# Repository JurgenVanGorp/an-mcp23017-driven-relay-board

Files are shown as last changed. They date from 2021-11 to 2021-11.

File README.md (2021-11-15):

Guide creation date: 13-Nov-2021

# An MCP23017 driven relay board for Home Assistant on a Raspberry Pi
A schematic and hardware board for an MCP23017 multi-I/O controller driven relays.

Previous topic: [Step 4: Controlling the MCP23017 from within Home-Assistant.](https://github.com/JurgenVanGorp/MCP23017-multi-I-O-Control-with-Raspberry-Pi-and-Home-Assistant)

## Introduction

In the previous topics it was shown how an MCP23017 can be used for controlling toggle relays with an MCP23017 multi-I/O chip. The examples made use of an MCP23017 chip on a breadboard. For real life usage we will need a PCB that can be properly installed in a rack.

This guide describes a simple PCB board in Eurocard format (10cm x 16cm) that allows connecting an MCP23017 to a Raspberry Pi with Home Assistant, over the I2C bus. The board has 15 open ended relays. The 16th output is used to drive an "identification" LED. It can be used to identify the board if you are using multiple boards, and for verification that the communication is working properly.

The board needs a 12V power supply. The 12V is converted to 5V on the board, and is also used to power the mini relays. With some modifications you can also use the board with 5V directly, but you would need to replace the relays with pin-compatible 5V relays. I am using 12V for the simple reason that all switches in my house operate on 12V. The translation to higher voltages is only done in the power box.

**WARNING** Even though the PCB board described below does provide you with physical segregation with relays, IT IS NOT SUITED FOR HIGH VOLTAGE OR HIGH CURRENT USE. The low voltage and high voltage lines on the PCB are not sufficiently separated on the PCB for safe use with high voltages. The board can be used with low-voltage (max 48V) toggle relays (aka teleruptors) at a maximum of 500 milliAmps.

## Using and changing the files in this repository

I have created the schematic and PCB in this repository with the open and free [KiCad EDA](https://www.kicad.org/) software. I cannot express enough how much I am grateful to [the developers](https://www.kicad.org/about/kicad/) of this PCB software. As far as I'm concerned the times of too-expensive PCB software are over.

The PCB file looks as follows.

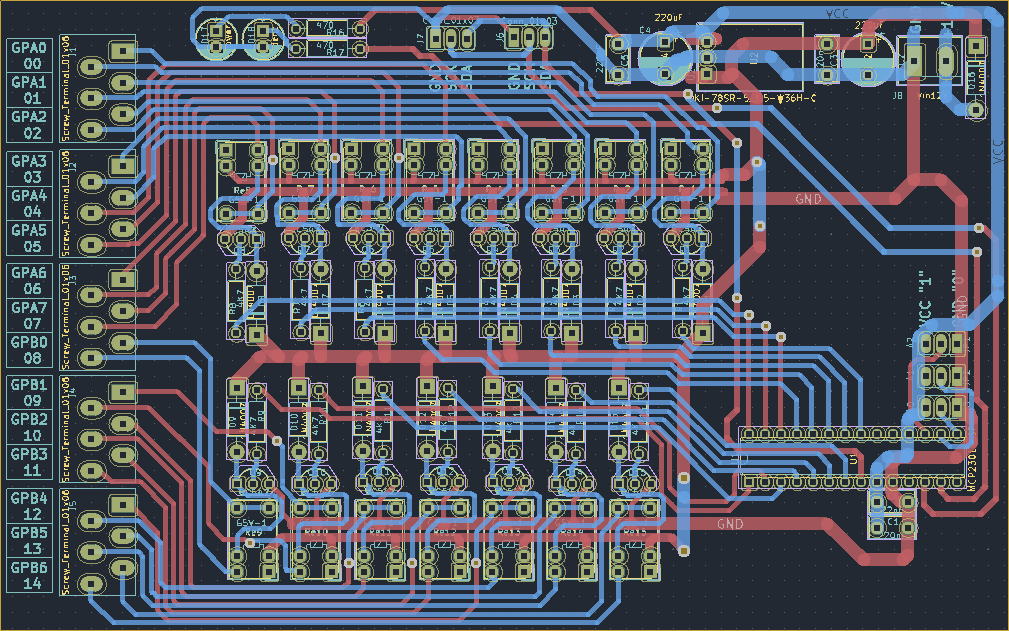
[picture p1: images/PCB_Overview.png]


The GERBER PCB Files are included in the package, so you don't need to compile these for yourself.

There are many companies that will be able to create the PCB files for you. My personal favorite is [Eurocircuits.eu](https://www.eurocircuits.com/), but that's a personal choice of course. You can also create your own PCBs; the PDF file is added in the repository. But let's be honest, ordering the PCB looks a lot more professional and will last longer.



**INFO** In honnesty: the image above does not fully match the PCB you can find in the repository. In this prototype I made use of RJ10 connectors for the I2C connections, but these connectors are difficult to find. If you find one, it will probably have a slightly footprint. For that reason I used 'standard' 3-pin connectors in the final PCB layout.

## Components used.

This is the list of components used, and where I have found them.

| Quantity | Component | Value | Source | ~cost/Piece |
|:---:|---|---:|---|---:|
| 1 | PCB Board | See Gerber files | [eurocircuits.eu](https://www.eurocircuits.eu) | € 35.00 | 
| 1 | IC | MCP23017 | [mouser.com](https://eu.mouser.com/ProductDetail/Microchip/MCP23017-E-SP?qs=sGAEpiMZZMsVgcksf1EMUq%252Bl%252ByrW%252Br2s) | € 1.35 |
| 2 | 14 pins socket | MCP23017 | [mouser.com](https://www.conrad.com/p/tru-components-ic-socket-contact-spacing-254-mm-762-mm-number-of-pins-14-1-pcs-1568704) | € 0.40 |
| 2 | Resistor | 470 |  |  | 
| 16 | Diode | 1N4007 | [conrad.com](https://www.conrad.com/p/diotec-si-rectifier-1n4007-do-204al-1000-v-1-a-162272) | € 0.09 | 
| 15 | Resistor | 4K7 | [conrad.com](https://www.conrad.com/p/tru-components-tc-mf0w4ff4701a50203-metal-film-resistor-47-k-axial-lead-0207-025-w-1-1-pcs-1585059) | € 0.10 | 
| 1 | Capacitor | 22nF  | [conrad.com](https://www.conrad.com/p/tru-components-tc-k22nf5-ceramic-capacitor-tht-22-nf-100-v-20-1-pcs-1589451) | € 0.10 | 
| 3 | Capacitor | 220nF | [conrad.com](https://www.conrad.com/p/kemet-c320c224m5u5ta-ceramic-capacitor-radial-lead-220-nf-50-v-20-l-x-w-x-h-508-x-318-x-584-mm-1-pcs-1420328) | € 0.60 | 
| 2 | Capacitor | 220uF | [conrad.com](https://www.conrad.com/p/europe-chemicon-eky-500ell221mj16s-electrolytic-capacitor-radial-lead-5-mm-220-f-50-v-20-x-h-10-mm-x-16-mm-1-pc-1505568) | € 0.50 | 
| 15 | Transistor | BC547 **(1)** | [conrad.com](https://www.conrad.com/search?search=140539&searchType=regular) | € 0.05 |
| 1 | 12V to 5V DC | OKI-78SR-5_1.5-W36H-C **(2)** | [mouser.com](https://eu.mouser.com/ProductDetail/Murata/OKI-78SR-5-15-W36H-C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) | € 3.64 | 
| 15 | Relay 12V | G5V-1-DC12 **(3)** | [mouser.com](https://eu.mouser.com/ProductDetail/Omron/G5V-1-DC12?qs=sGAEpiMZZMv0NwlthflBi%2Fae0vpIDW5L) | € 1.45 |
| 3 | Jumper | N/A | e.g. [conrad.com](https://www.conrad.com/p/tru-components-shorting-jumper-contact-spacing-254-mm-pins-per-row2-content-100-pcs-1693950) | € 0.35 | 
| 1 | Connector 1x2 | DG350-3.5-03P | [conrad.com](https://www.conrad.com/p/degson-dg350-35-02p-14-00ah-200-screw-terminal-2-mm-number-of-pins-2-green-200-pcs-1595136) | € 0.22 | 
| 2 | Connector 1x3 | DG350-3.5-02P | [conrad.com](https://www.conrad.com/p/degson-dg350-35-03p-14-00ah-200-screw-terminal-2-mm-number-of-pins-3-green-200-pcs-1595217) | € 0.32 | 
| 5 | 1x6 Spring connector | PTR 54191060051E | [conrad.com](https://www.conrad.com/p/ptr-54191060051e-spring-loaded-terminal-075-mm-number-of-pins-6-pebble-grey-1-pcs-569770) | € 0.36 | 
| 1 | LED "IDENT"  | Green 5 mm | [conrad.com](https://www.conrad.com/p/vishay-tlhr-5400-led-wired-super-red-circular-5-mm-10-mcd-30-30-ma-2-v-184389) | € 0.20 | 
| 1 | LED "POWER"  | Red 5 mm | [conrad.com](https://www.conrad.com/p/kingbright-l-7113id-led-wired-red-circular-5-mm-45-mcd-30-20-ma-2-v-180139) | € 0.20 |
| TOTAL | | | | ~€ 74 |

**(1)** Also known as 2N3904 / BC547 / PN2222 / 2N4401 / NTE123AP. Make your pick, this is a "standard" NPN transistor. 

**(2)** The OKI-78SR is a 12V DC to 5V DC converter. It is pin-compatible with an [LM7805](https://eu.mouser.com/ProductDetail/Texas-Instruments/LM7805CT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). The current drawn is very low, so feel free to replace it with an LM7805 if you prefer.

**(3)** You can also power the board with 5V. In that case you will need to bridge the DC/DC converter and replace the 12V relays with the 5V [G5V-1-DC5 version](https://eu.mouser.com/ProductDetail/Omron/G5V-1-2-DC5?qs=sGAEpiMZZMsKEdP9slC0YbH1hXJZnuIH7AhUMezYhKg%3D).

The assembled board should look something like the following. Please mind that the below board is the prototype and looks slightly different from the PCB.

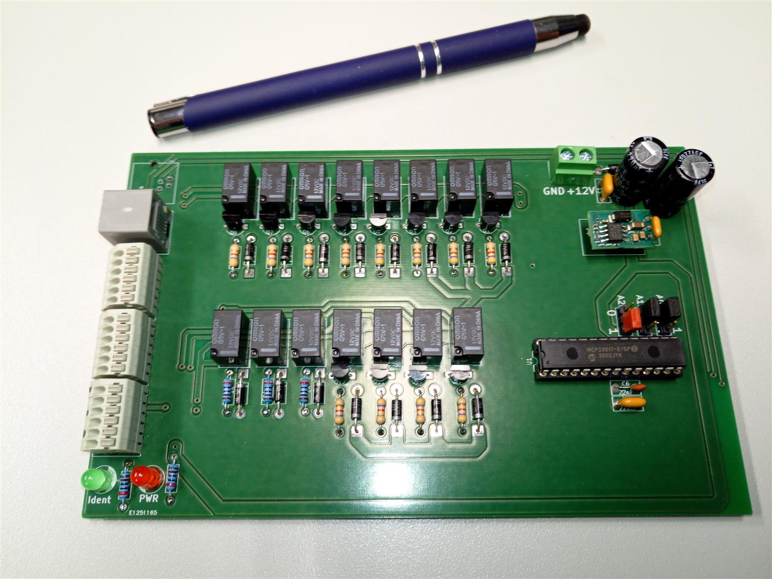
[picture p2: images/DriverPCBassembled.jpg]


## Schematic decription

The overall schematic looks as follows. You can [download the shematic in PDF format here](https://github.com/JurgenVanGorp/an-mcp23017-driven-relay-board/blob/main/DOMOTICS%20MCP23017%20Relay%20Control/PCB%20Layouts.pdf).

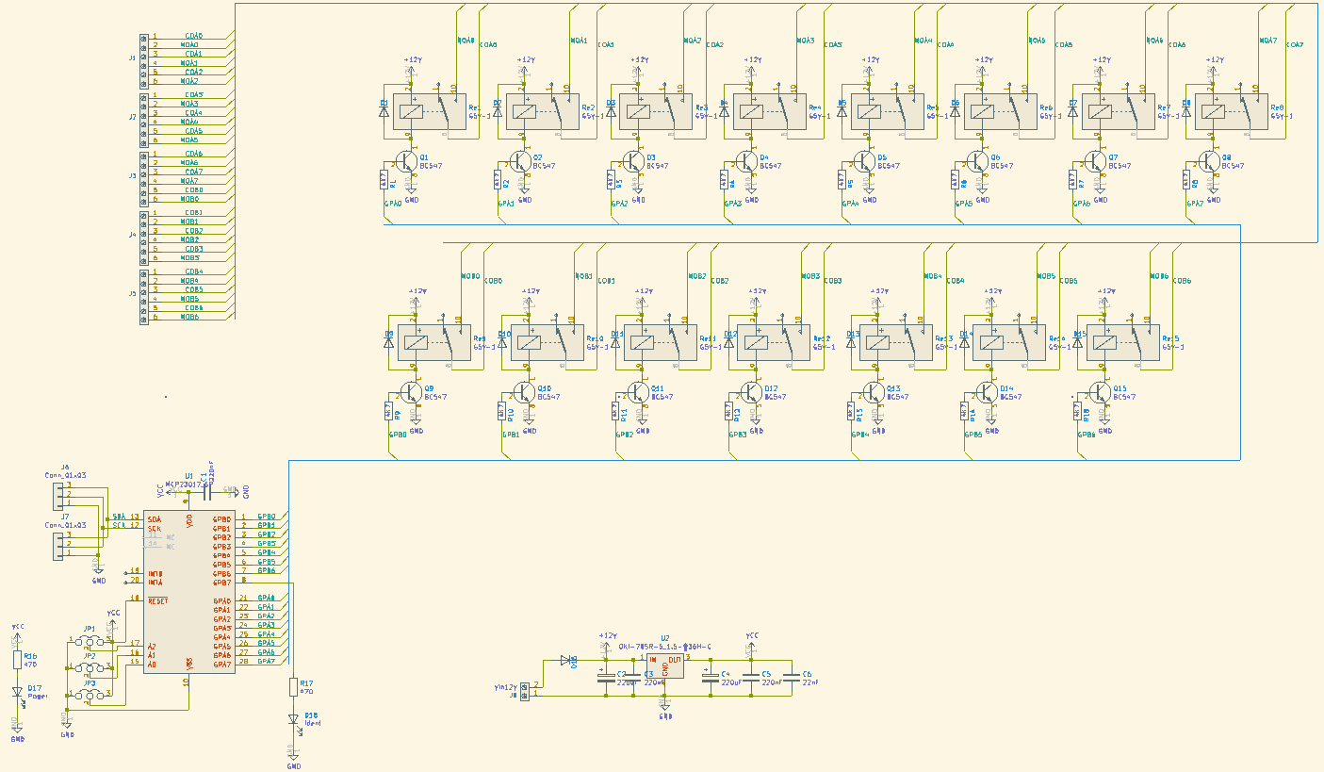
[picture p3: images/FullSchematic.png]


True, this is a bit crowded, and not easy to follow. So, let's highlight a few details here. The easy part is the top left section, containing the connector block with five 6-pins spring connectors.

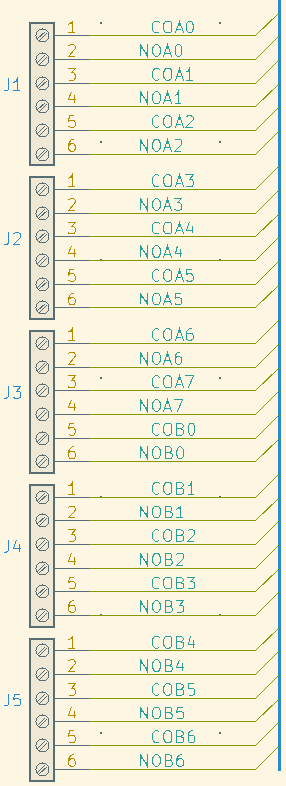
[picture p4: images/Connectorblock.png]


Then, let's have a look at one of the fifteen relay configurations you can find in the top right section of the schematic.

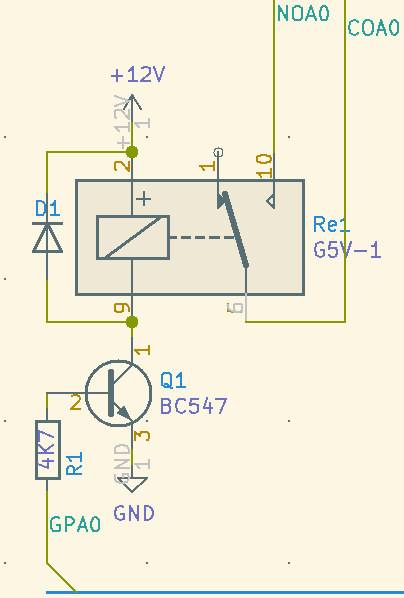
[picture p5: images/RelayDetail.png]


All fifteen relays have the same straight-forward configuration.
* The NO (Normally-Open) and CO (Common) pins of the relay are routed to the connector block. I.e. 'in rest' the outputs are not connected.
* Resistor R1 is connected to the output of one of the MCP23017 pins.
* Transistor T1 is used as a switch. Strictly spoken, any pin-compatible NPN transistor can be used here.
* Diode D1 protects the transistor when switching off the relay. Since this is a coil relay, suddenly switching off the relay can result in a reverse voltage peak which can potentially damage the transistor. Diode D1 make sure that a reverse current in the coil is shortcut.

Finally, let's look at the MCP23017 block in more detail.
* The output pins of both GPA and GPB are routed to the relay blocks. 
* GPB7 ("pin 15" in Home Assistant) is connected to the "Identification" LED D18 and can be used to identify the board and test the MCP23017 operation.
* Connectors J6 and J7 are used to connect the I2C pins to the Raspberry Pi. Remark that both connectors are configured fully parallel, so that the connectors can be used to cascade multiple boards.
* Jumpers JP1 .. JP3 are used as the address selectors.
* LED D17 is just connected to the +5V output and can be used to verify the power.

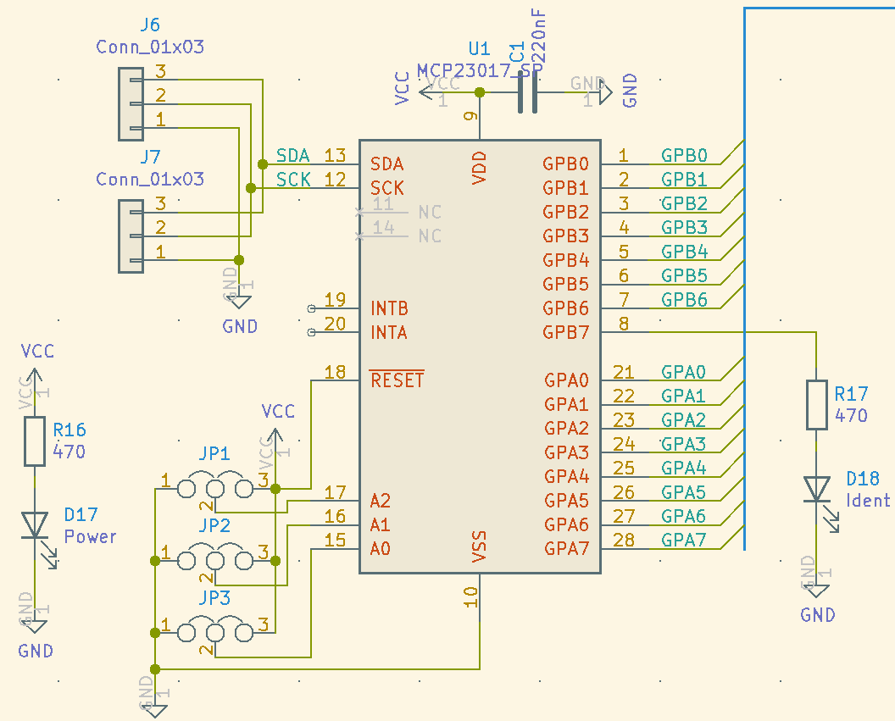
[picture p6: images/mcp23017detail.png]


## Mounting the PCB Board

The PCBs are 10cm x 16cm which allows mounting them in a standard EuroRack, as in the image below. If you want to know more about Euroracks, [RS gives a nice overview here](https://nl.rs-online.com/web/generalDisplay.html?id=ideas-and-advice/eurocards-pcb-guide). They also sell different types of enclosures.



An alternate way for mounting the board, is a DIN rail case. The components for a DIN rail mount are e.g. the following.

| Quantity | Component | Description | Source | ~cost/Piece |
|:---:|---|---|---|---:|
| 2 or 3 | Phoenix Contact UM108-FE | DIN rail mount | [conrad.com](https://www.conrad.com/p/phoenix-contact-um108-fe-din-rail-casing-base-1075-plastic-10-pcs-454634) | € 0.70 | 
| 1 | Phoenix Contact UM108-SEFE/R | Right side panel | [conrad.com](https://www.conrad.com/p/phoenix-contact-um108-sefer-din-rail-casing-side-panel-plastic-10-pcs-453303) | € 1.00 |
| 1 | Phoenix Contact UM108-SEFE/R | Left side panel | [conrad.com](https://www.conrad.com/search?search=459039&searchType=regular) | € 1.00 |
| 1 | Phoenix Contact UM100-PROFIL 100CM | back plate (1m)  | [conrad.com](https://www.conrad.com/p/phoenix-contact-um100-profil-100cm-din-rail-casing-plastic-1-pcs-456207) | € 30.00 |

Next topic: [A sensor (relay) board for sensing 240V high power states with an MCP23017.](https://github.com/JurgenVanGorp/an-MCP23017-driven-high-voltage-sensor-board)

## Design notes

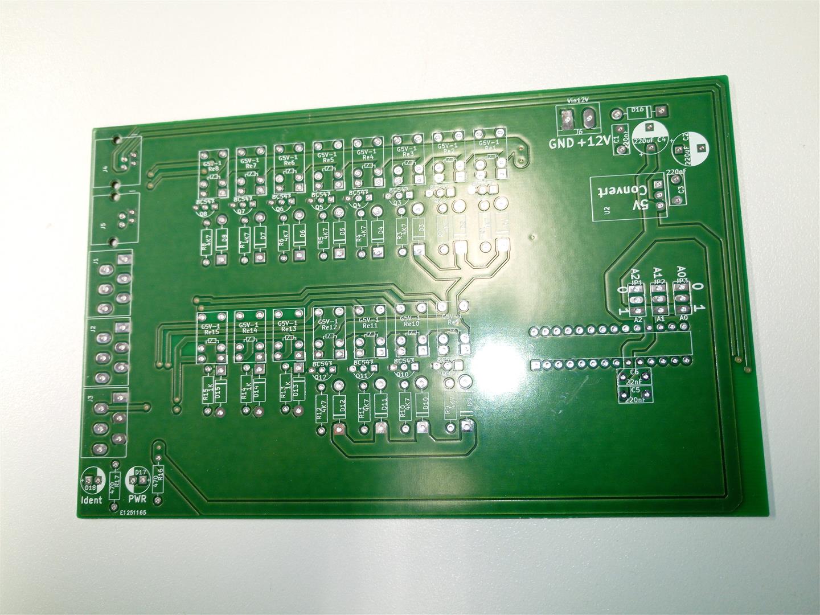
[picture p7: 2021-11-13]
images/DriverPCB.jpg

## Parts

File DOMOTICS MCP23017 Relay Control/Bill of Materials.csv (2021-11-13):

Id | Designator | Package | Quantity | Designation | Supplier and ref
1 | U1 | DIP-28_W7.62mm | 1 | MCP23017_SP
2 | U2 | Converter_DCDC_muRata_OKI-78SR_Horizontal | 1 | OKI-78SR-5_1.5-W36H-C
3 | Re15,Re14,Re13,Re12,Re11,Re10,Re9,Re8,Re7,Re6,Re5,Re4,Re3,Re2,Re1 | Relais_SPDT_Omron_G5V-1 | 15 | G5V-1
4 | R17,R16 | R_Radial | 2 | 470
5 | R15,R14,R13,R12,R11,R10,R9,R8,R7,R6,R5,R4,R3,R2,R1 | R_Radial | 15 | 4K7
6 | Q15,Q14,Q13,Q12,Q11,Q10,Q9,Q8,Q7,Q6,Q5,Q4,Q3,Q2,Q1 | TO-92_Inline_Wide_Jurgen | 15 | BC547
7 | JP3 | Connector_1x3_Normal | 1 | A0
8 | JP2 | Connector_1x3_Normal | 1 | A1
9 | JP1 | Connector_1x3_Normal | 1 | A2
10 | J8 | TerminalBlock_bornier-2_P5.08mm_jurgen | 1 | Vin12V
11 | J7,J6 | Connector_1x3_Normal | 2 | Conn_01x03
12 | J5,J4,J3,J2,J1 | Connector_1x6_ZigZag | 5 | Screw_Terminal_01x06
13 | D18 | LED_Radial_D6.3mm_P2.50mm_Jurgen | 1 | Ident
14 | D17 | LED_Radial_D6.3mm_P2.50mm_Jurgen | 1 | Power
15 | D16,D15,D14,D13,D12,D11,D10,D9,D8,D7,D6,D5,D4,D3,D2,D1 | Diode10.16mm_Horizontal_Jurgen | 16 | 1N4007
16 | C6 | Capacitor | 1 | 22nF
17 | C5,C3,C1 | Capacitor | 3 | 220nF
18 | C4,C2 | CP_Radial_D8.0mm_P5.00mm | 2 | 220uF

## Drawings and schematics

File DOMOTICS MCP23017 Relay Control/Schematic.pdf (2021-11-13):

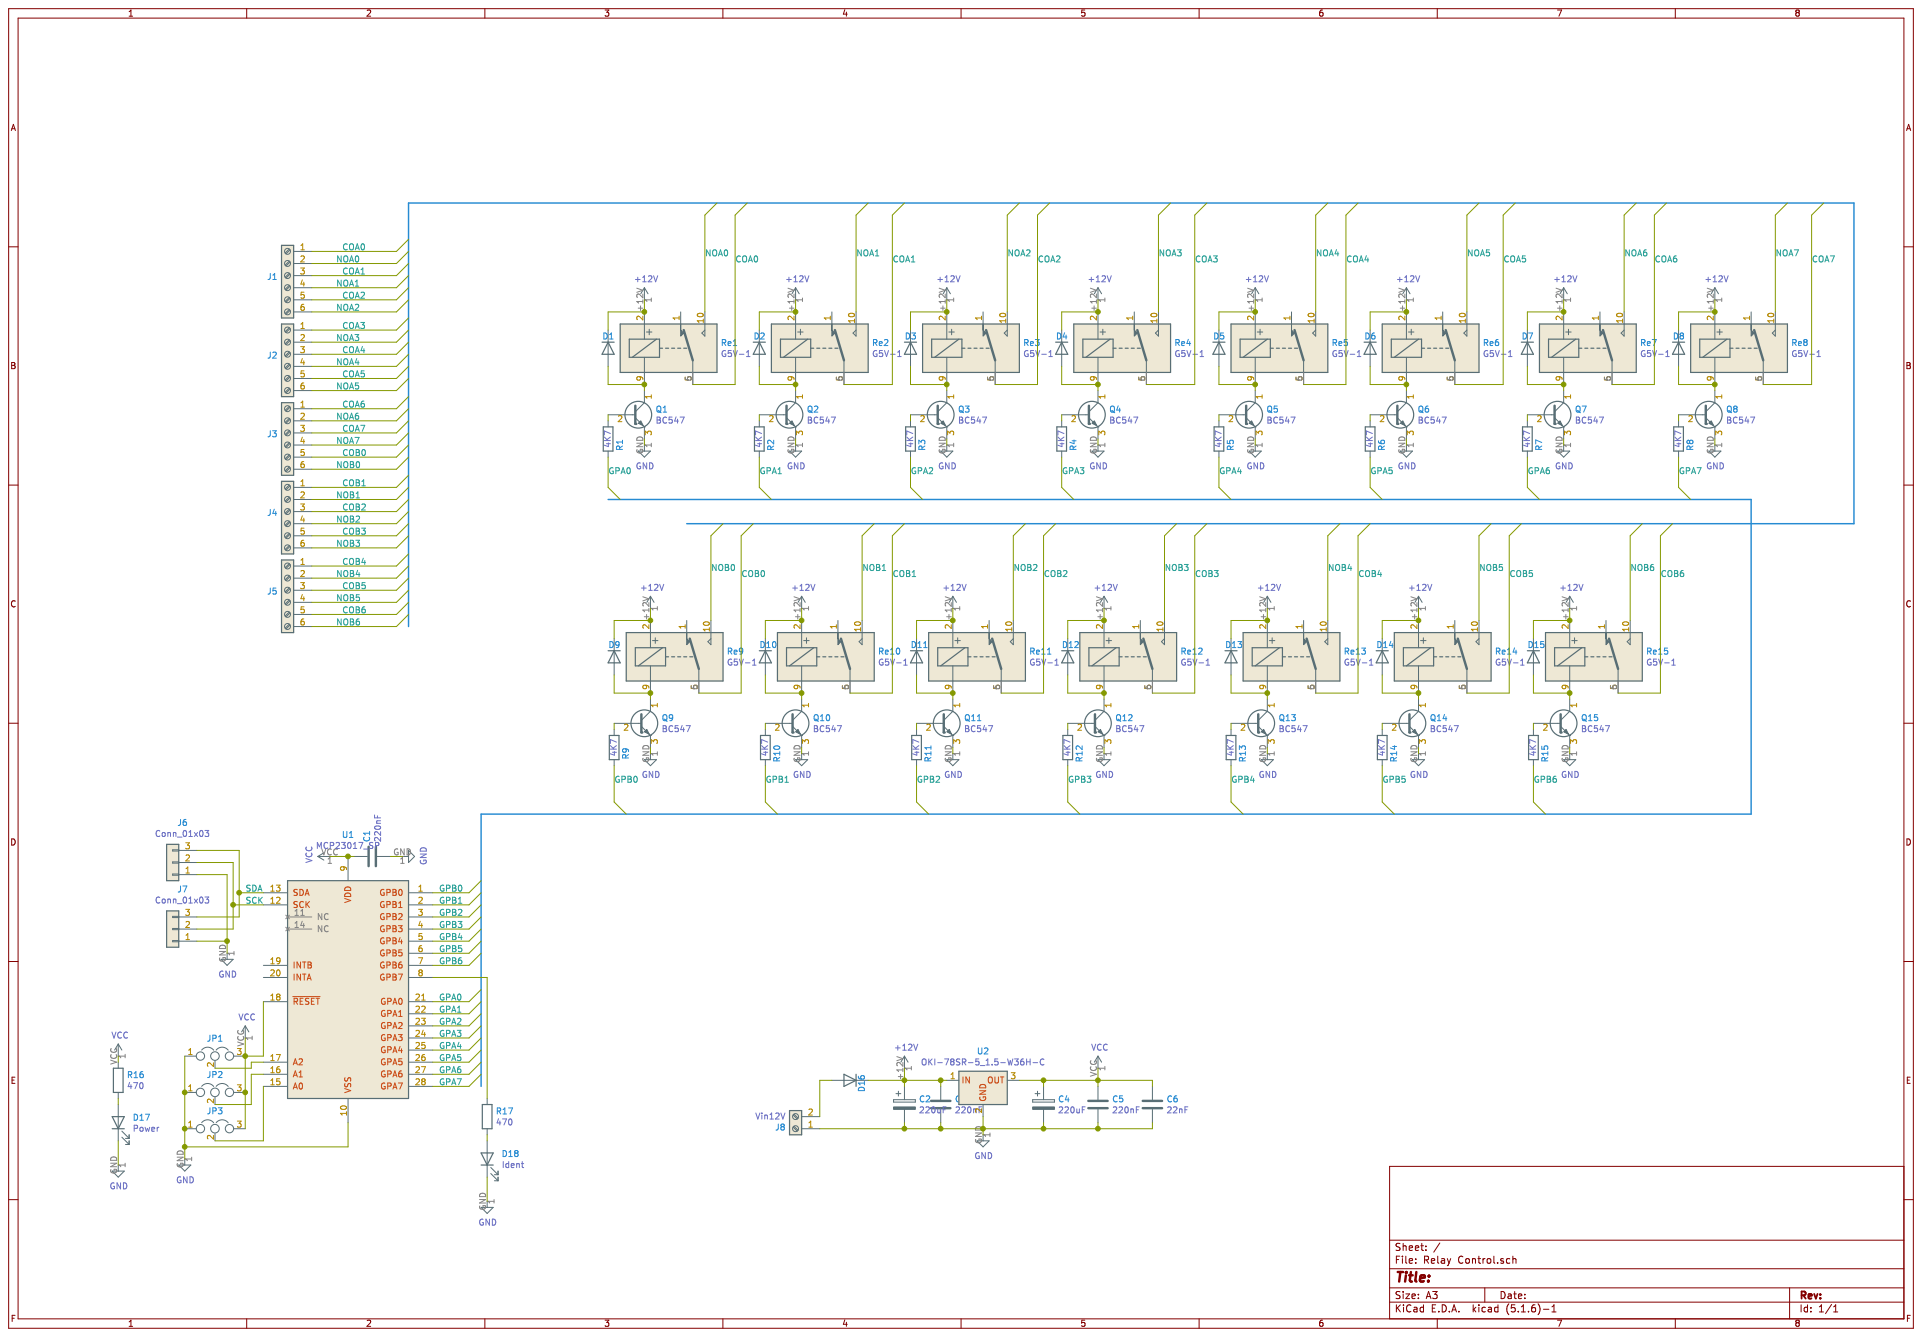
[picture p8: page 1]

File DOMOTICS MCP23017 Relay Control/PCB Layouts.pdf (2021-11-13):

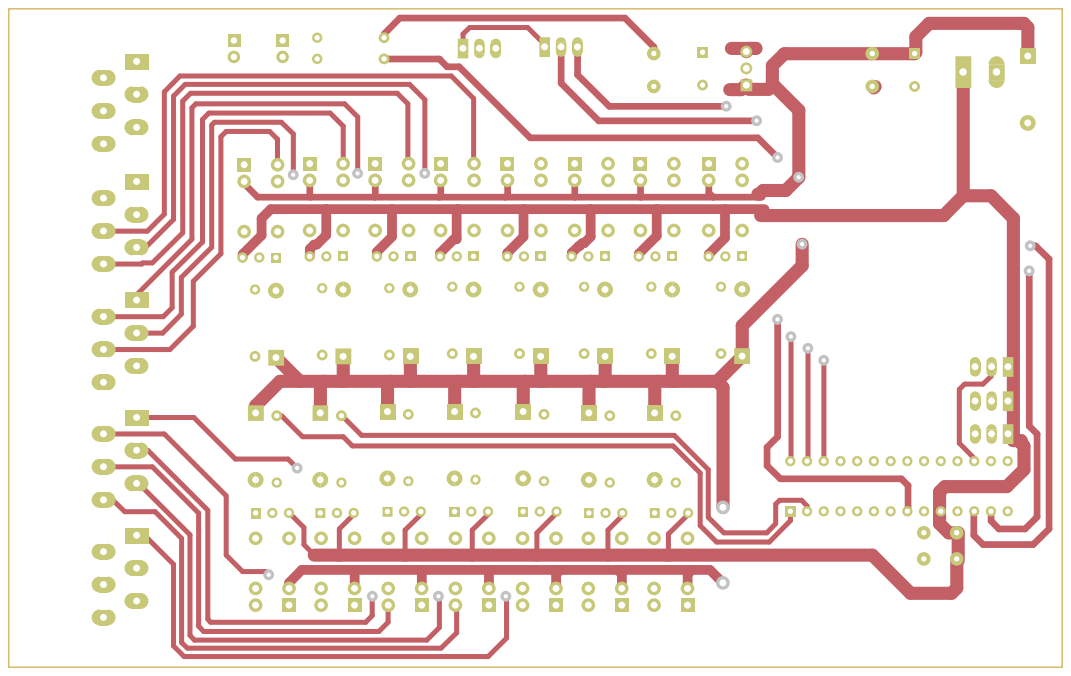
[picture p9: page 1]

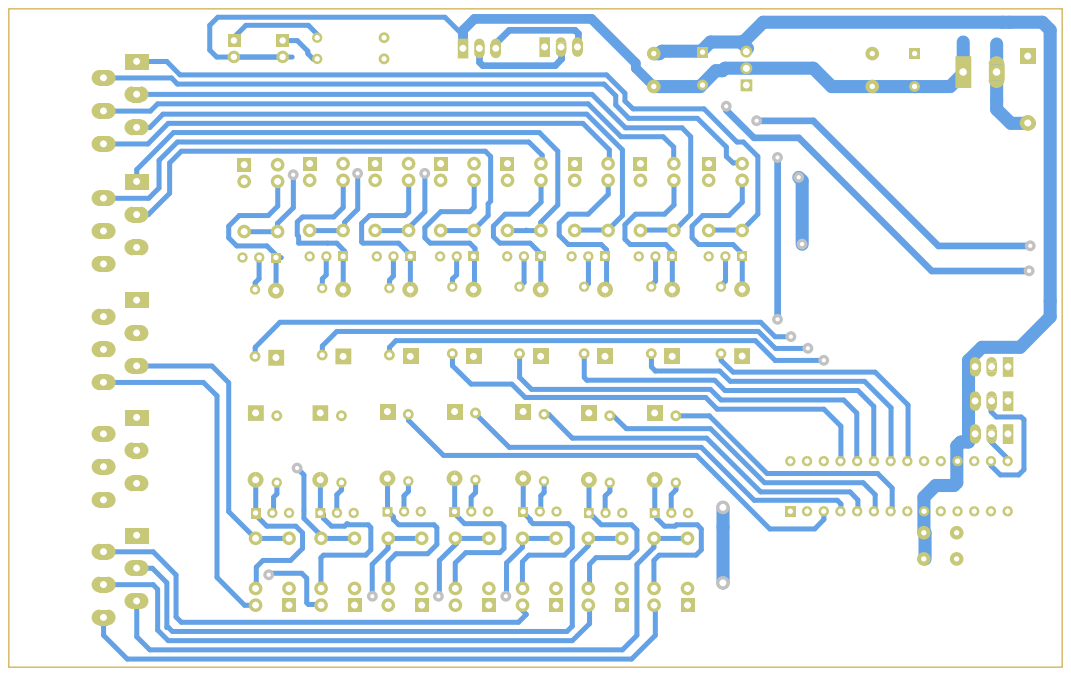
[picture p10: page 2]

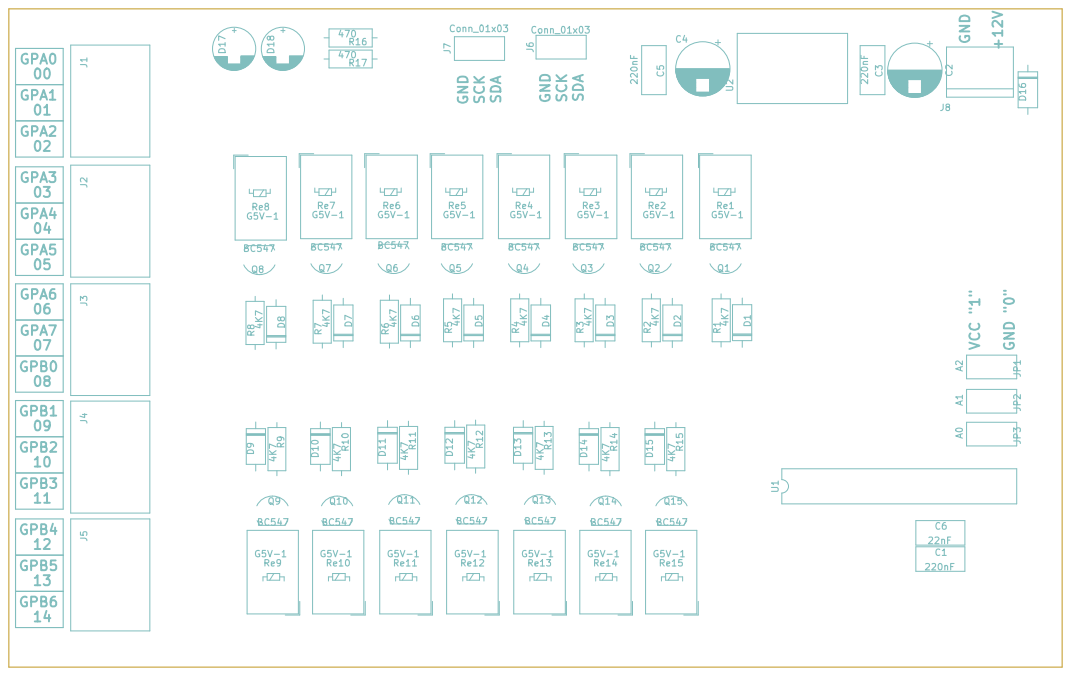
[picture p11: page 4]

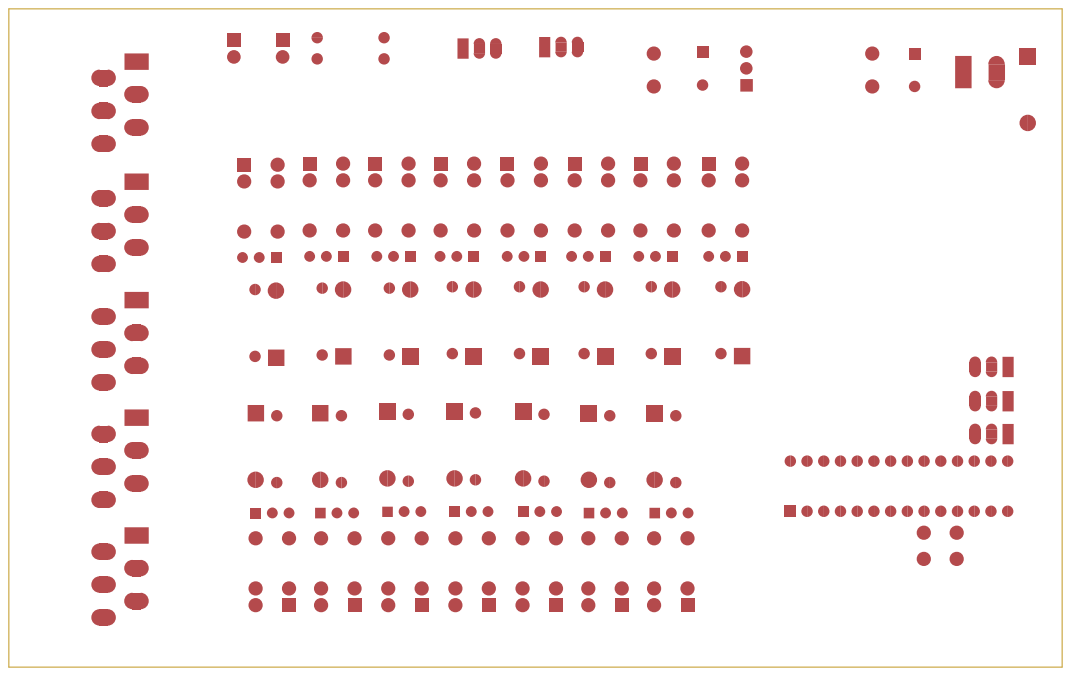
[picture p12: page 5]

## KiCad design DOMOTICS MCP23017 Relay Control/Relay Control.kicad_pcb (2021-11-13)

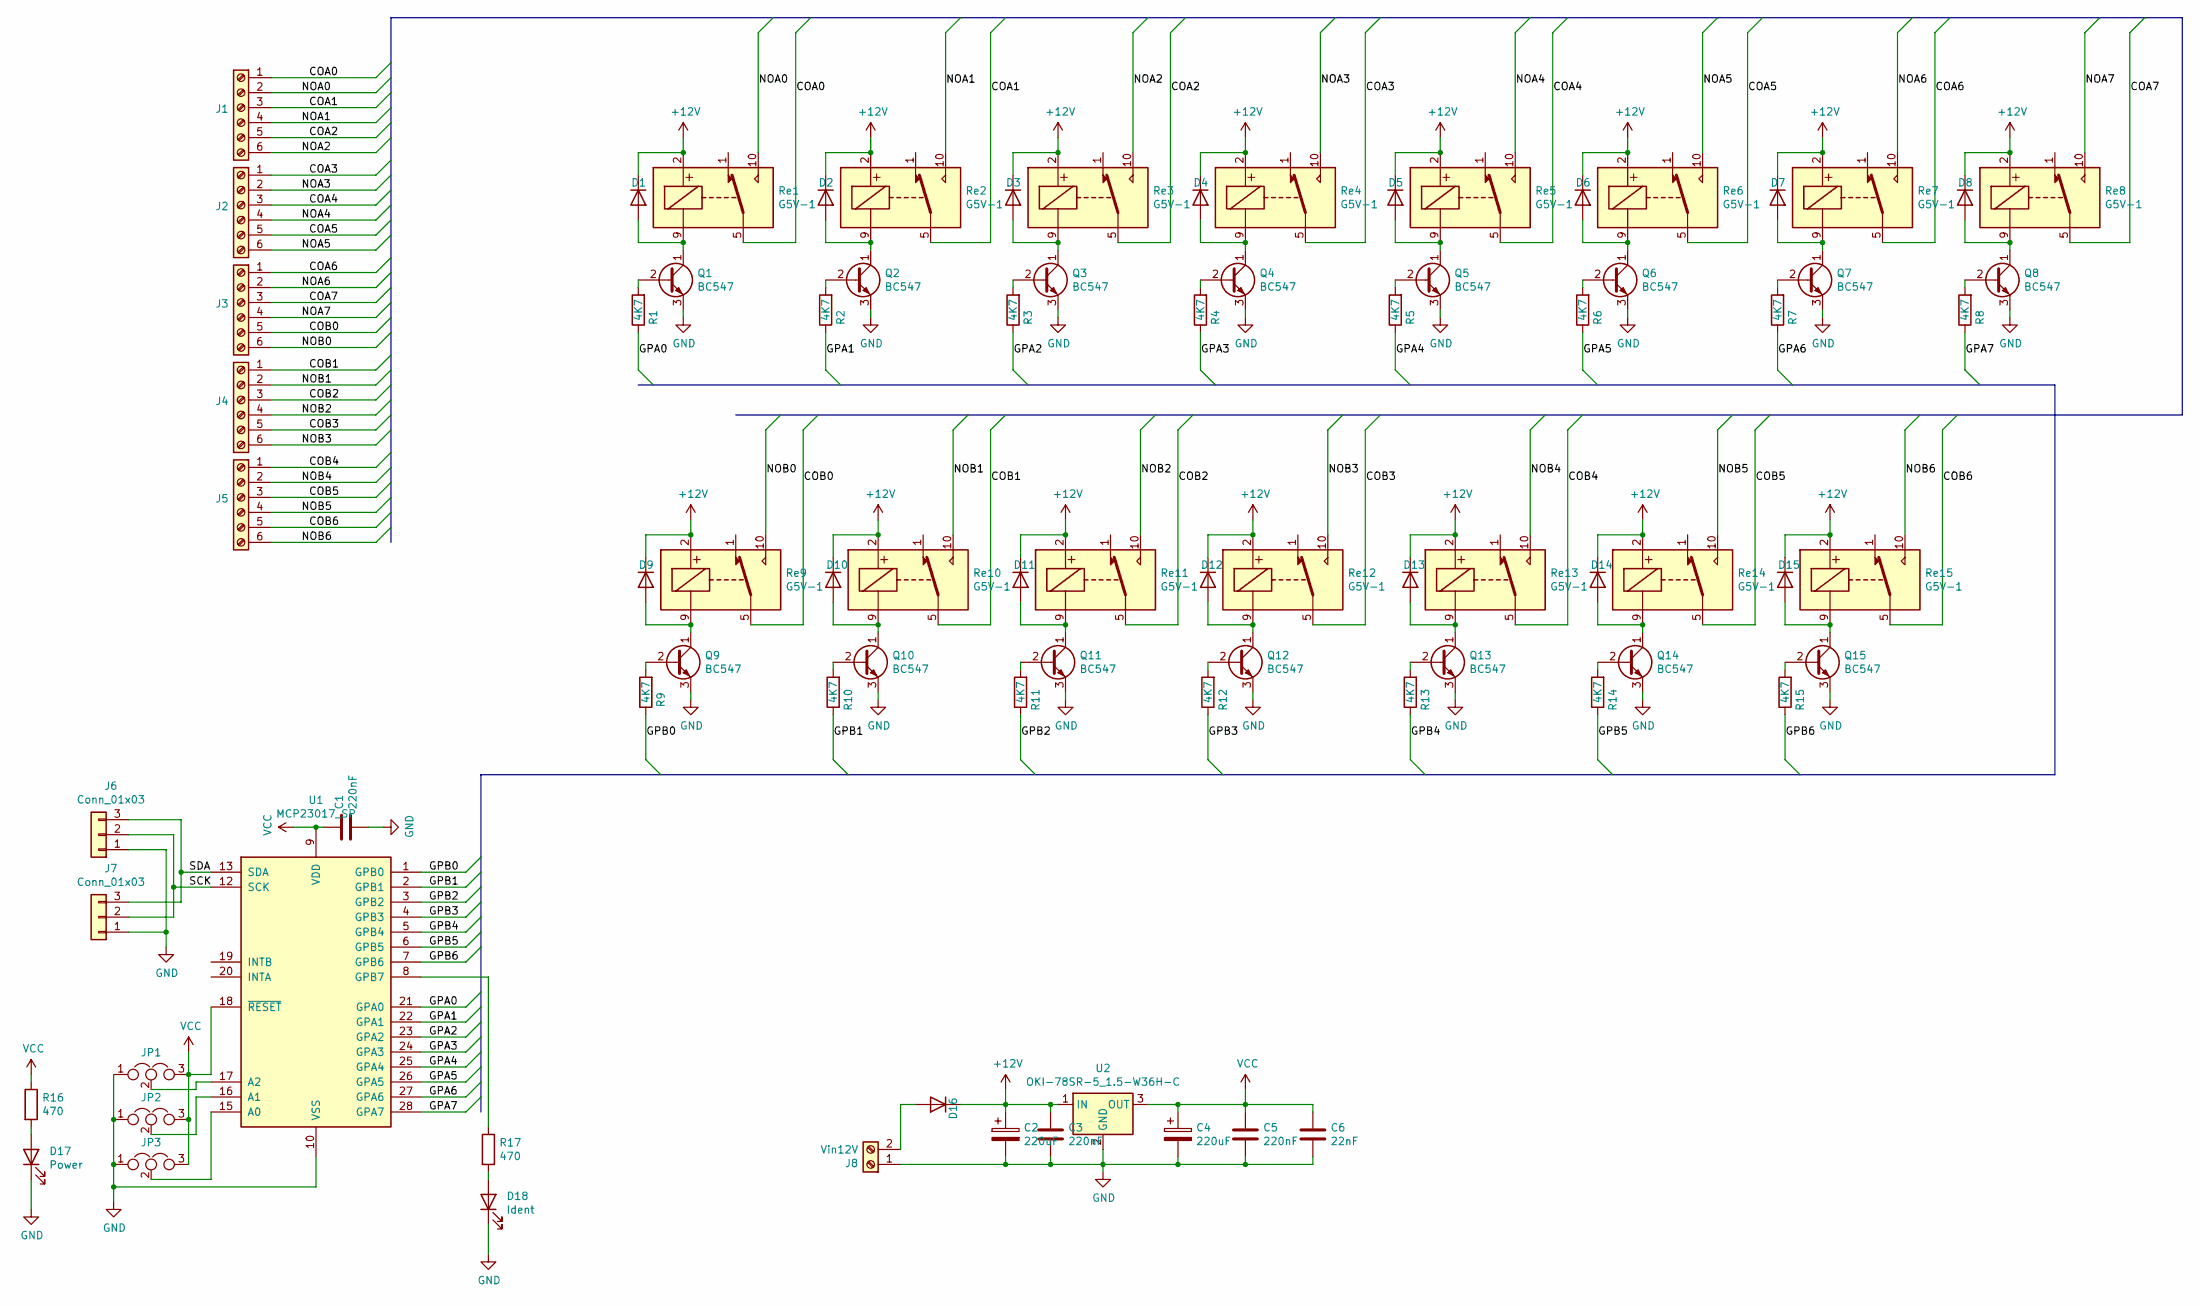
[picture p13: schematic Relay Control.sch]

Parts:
C1, C3, C5: 220nF; Capacitor
C2, C4: 220uF; CP_Radial_D8.0mm_P5.00mm
C6: 22nF; Capacitor
D1, D2, D3, D4, D5, D6, D7, D8, D9, D10, D11, D12, D13, D14, D15, D16: 1N4007; Diode10.16mm_Horizontal_Jurgen
D17: Power; LED_Radial_D6.3mm_P2.50mm_Jurgen
D18: Ident; LED_Radial_D6.3mm_P2.50mm_Jurgen
J1, J2, J3, J4, J5: Screw_Terminal_01x06; Connector_1x6_ZigZag
J6, J7: Conn_01x03; Connector_1x3_Normal
J8: Vin12V; TerminalBlock_bornier-2_P5.08mm_jurgen
JP1: A2; Connector_1x3_Normal
JP2: A1; Connector_1x3_Normal
JP3: A0; Connector_1x3_Normal
Q1, Q2, Q3, Q4, Q5, Q6, Q7, Q8, Q9, Q10, Q11, Q12, Q13, Q14, Q15: BC547; TO-92_Inline_Wide_Jurgen
R1, R2, R3, R4, R5, R6, R7, R8, R9, R10, R11, R12, R13, R14, R15: 4K7; R_Radial
R16, R17: 470; R_Radial
Re1, Re2, Re3, Re4, Re5, Re6, Re7, Re8, Re9, Re10, Re11, Re12, Re13, Re14, Re15: G5V-1; Relais_SPDT_Omron_G5V-1
U1: MCP23017_SP; DIP-28_W7.62mm
U2: OKI-78SR-5_1.5-W36H-C; Converter_DCDC_muRata_OKI-78SR_Horizontal

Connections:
+12V: C2.1, C3.1, D1.1 (K), D2.1 (K), D3.1 (K), D4.1 (K), D5.1 (K), D6.1 (K), D7.1 (K), D8.1 (K), D9.1 (K), D10.1 (K), D11.1 (K), D12.1 (K), D13.1 (K), D14.1 (K), D15.1 (K), D16.1 (K), Re1.2, Re2.2, Re3.2, Re4.2, Re5.2, Re6.2, Re7.2, Re8.2, Re9.2, Re10.2, Re11.2, Re12.2, Re13.2, Re14.2, Re15.2, U2.1 (IN)
/COA0: J1.1, Re1.5, Re1.6
/COA1: J1.3, Re2.5, Re2.6
/COA2: J1.5, Re3.5, Re3.6
/COA3: J2.1, Re4.5, Re4.6
/COA4: J2.3, Re5.5, Re5.6
/COA5: J2.5, Re6.5, Re6.6
/COA6: J3.1, Re7.5, Re7.6
/COA7: J3.3, Re8.5, Re8.6
/COB0: J3.5, Re9.5, Re9.6
/COB1: J4.1, Re10.5, Re10.6
/COB2: J4.3, Re11.5, Re11.6
/COB3: J4.5, Re12.5, Re12.6
/COB4: J5.1, Re13.5, Re13.6
/COB5: J5.3, Re14.5, Re14.6
/COB6: J5.5, Re15.5, Re15.6
/GPA0: R1.1, U1.21 (GPA0)
/GPA1: R2.1, U1.22 (GPA1)
/GPA2: R3.1, U1.23 (GPA2)
/GPA3: R4.1, U1.24 (GPA3)
/GPA4: R5.1, U1.25 (GPA4)
/GPA5: R6.1, U1.26 (GPA5)
/GPA6: R7.1, U1.27 (GPA6)
/GPA7: R8.1, U1.28 (GPA7)
/GPB0: R9.1, U1.1 (GPB0)
/GPB1: R10.1, U1.2 (GPB1)
/GPB2: R11.1, U1.3 (GPB2)
/GPB3: R12.1, U1.4 (GPB3)
/GPB4: R13.1, U1.5 (GPB4)
/GPB5: R14.1, U1.6 (GPB5)
/GPB6: R15.1, U1.7 (GPB6)
/NOA0: J1.2, Re1.10
/NOA1: J1.4, Re2.10
/NOA2: J1.6, Re3.10
/NOA3: J2.2, Re4.10
/NOA4: J2.4, Re5.10
/NOA5: J2.6, Re6.10
/NOA6: J3.2, Re7.10
/NOA7: J3.4, Re8.10
/NOB0: J3.6, Re9.10
/NOB1: J4.2, Re10.10
/NOB2: J4.4, Re11.10
/NOB3: J4.6, Re12.10
/NOB4: J5.2, Re13.10
/NOB5: J5.4, Re14.10
/NOB6: J5.6, Re15.10
/SCK: J6.2, J7.2, U1.12 (SCK)
/SDA: J6.3, J7.3, U1.13 (SDA)
GND: C1.2, C2.2, C3.2, C4.2, C5.2, C6.2, D17.1 (K), D18.1 (K), J6.1, J7.1, J8.1, JP1.1, JP2.1, JP3.1, Q1.3 (E), Q2.3 (E), Q3.3 (E), Q4.3 (E), Q5.3 (E), Q6.3 (E), Q7.3 (E), Q8.3 (E), Q9.3 (E), Q10.3 (E), Q11.3 (E), Q12.3 (E), Q13.3 (E), Q14.3 (E), Q15.3 (E), U1.10 (VSS), U2.2 (GND)
unnamed: D1.2 (A), Q1.1 (C), Re1.9
unnamed: D2.2 (A), Q2.1 (C), Re2.9
unnamed: D3.2 (A), Q3.1 (C), Re3.9
unnamed: D4.2 (A), Q4.1 (C), Re4.9
unnamed: D5.2 (A), Q5.1 (C), Re5.9
unnamed: D6.2 (A), Q6.1 (C), Re6.9
unnamed: D7.2 (A), Q7.1 (C), Re7.9
unnamed: D8.2 (A), Q8.1 (C), Re8.9
unnamed: D9.2 (A), Q9.1 (C), Re9.9
unnamed: D10.2 (A), Q10.1 (C), Re10.9
unnamed: D11.2 (A), Q11.1 (C), Re11.9
unnamed: D12.2 (A), Q12.1 (C), Re12.9
unnamed: D13.2 (A), Q13.1 (C), Re13.9
unnamed: D14.2 (A), Q14.1 (C), Re14.9
unnamed: D15.2 (A), Q15.1 (C), Re15.9
unnamed: D16.2 (A), J8.2
unnamed: D17.2 (A), R16.2
unnamed: D18.2 (A), R17.2
unnamed: JP1.2, U1.17 (A2)
unnamed: JP2.2, U1.16 (A1)
unnamed: JP3.2, U1.15 (A0)
unnamed: Q1.2 (B), R1.2
unnamed: Q2.2 (B), R2.2
unnamed: Q3.2 (B), R3.2
unnamed: Q4.2 (B), R4.2
unnamed: Q5.2 (B), R5.2
unnamed: Q6.2 (B), R6.2
unnamed: Q7.2 (B), R7.2
unnamed: Q8.2 (B), R8.2
unnamed: Q9.2 (B), R9.2
unnamed: Q10.2 (B), R10.2
unnamed: Q11.2 (B), R11.2
unnamed: Q12.2 (B), R12.2
unnamed: Q13.2 (B), R13.2
unnamed: Q14.2 (B), R14.2
unnamed: Q15.2 (B), R15.2
unnamed: R17.1, U1.8 (GPB7)
VCC: C1.1, C4.1, C5.1, C6.1, JP1.3, JP2.3, JP3.3, R16.1, U1.9 (VDD), U1.18 (~RESET~), U2.3 (OUT)

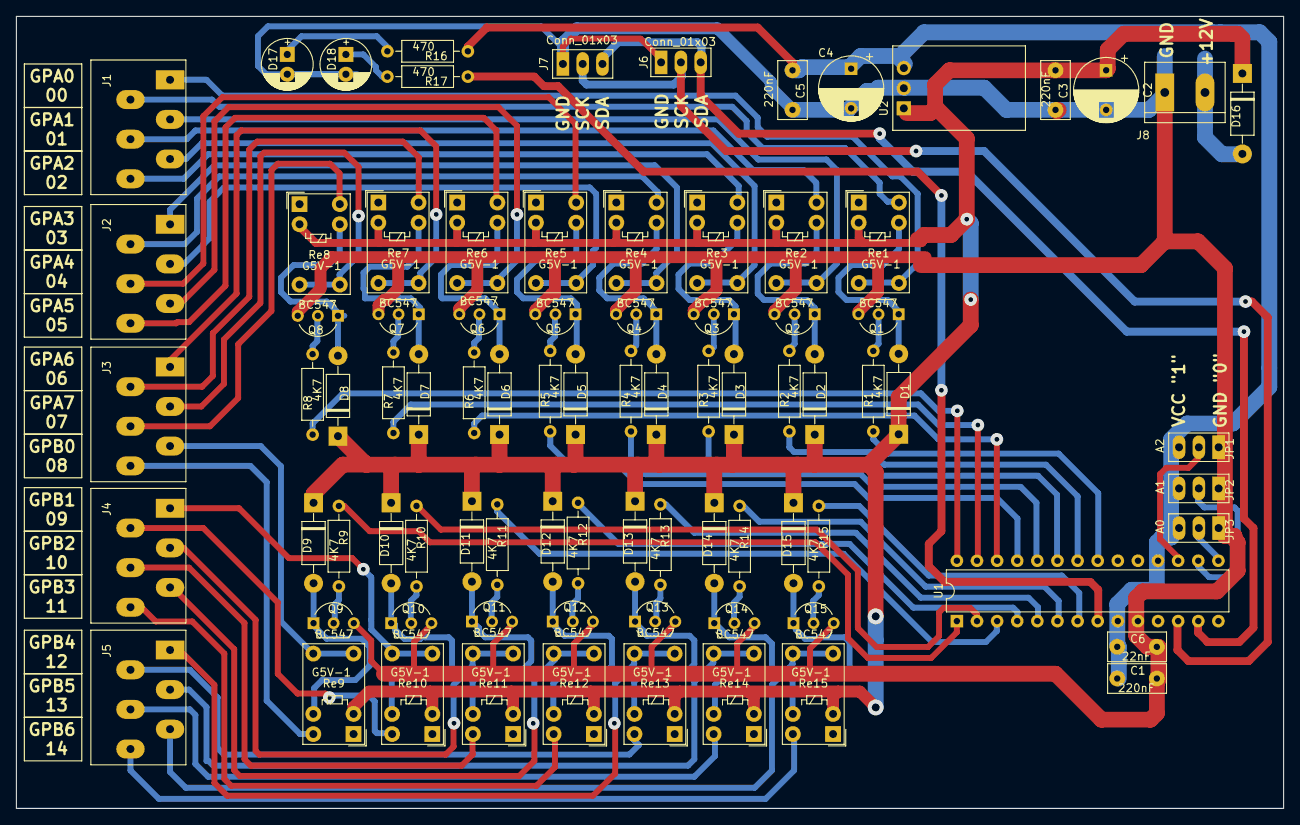
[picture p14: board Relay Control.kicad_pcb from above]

Board: 2 copper layers, 160.0 x 100.0 mm, 84 parts (0 on the bottom side), 87 nets.

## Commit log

2021-11-13 Schematics and PCB layout
    [Relay Control-B_Cu.gbl, Relay Control-B_Mask.gbs, Relay Control-B_Paste.gbp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]
2021-11-13 BoM updated
